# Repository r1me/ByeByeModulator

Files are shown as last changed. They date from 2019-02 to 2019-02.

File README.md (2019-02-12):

# ByeByeModulator
Modulator replacement for Commodore 64. The idea of this small board is to improve picture quality by removing noise that is caused by an RF modulator and its old electronic components. Including capacitors that can't be accessed easily for replacement, without desoldering a modulator first.  
This board is designed for, and tested with **250469 rev. B motherboard**. Do **NOT** even attempt to install it in other motherboards i.e. the one with 656x VIC-II chip. I'm not responsible for any damage.

## Board
It is a single sided, DIY friendly board.  
[Schematic](ByeByeModulator-schematic.pdf)  
[Back side for print](ByeByeModulator-board.png)  
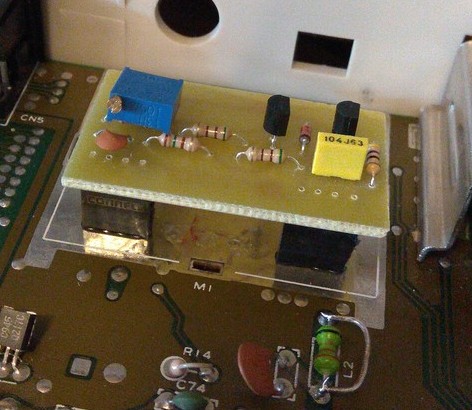
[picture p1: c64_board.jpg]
board-installed
  

## Results
Before & after
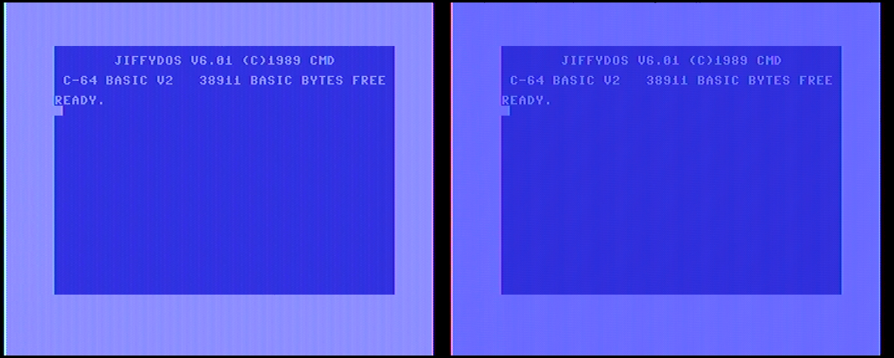
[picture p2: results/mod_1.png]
result-1
  
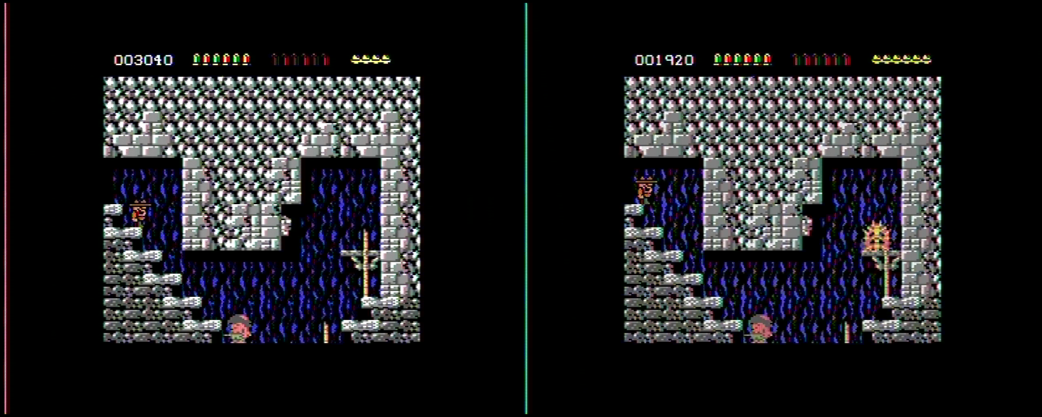
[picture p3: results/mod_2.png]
result-2
  
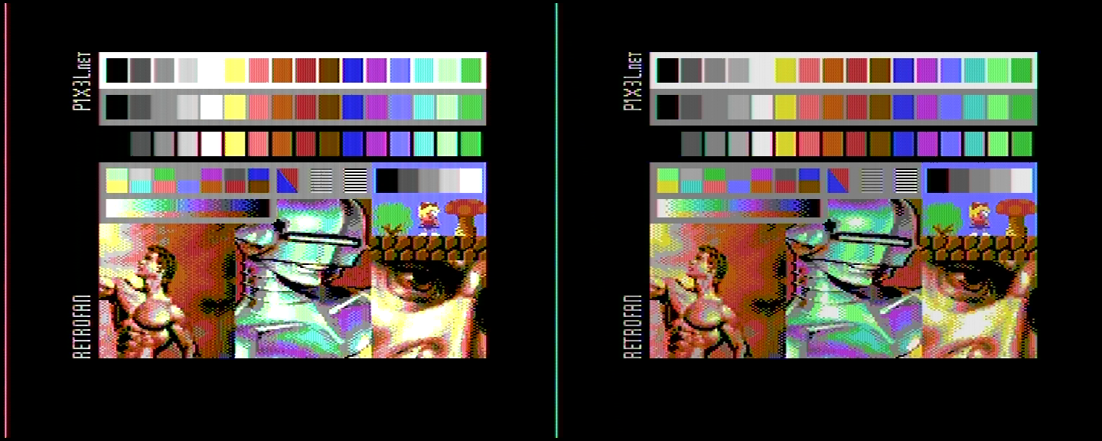
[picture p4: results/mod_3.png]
result-3
  
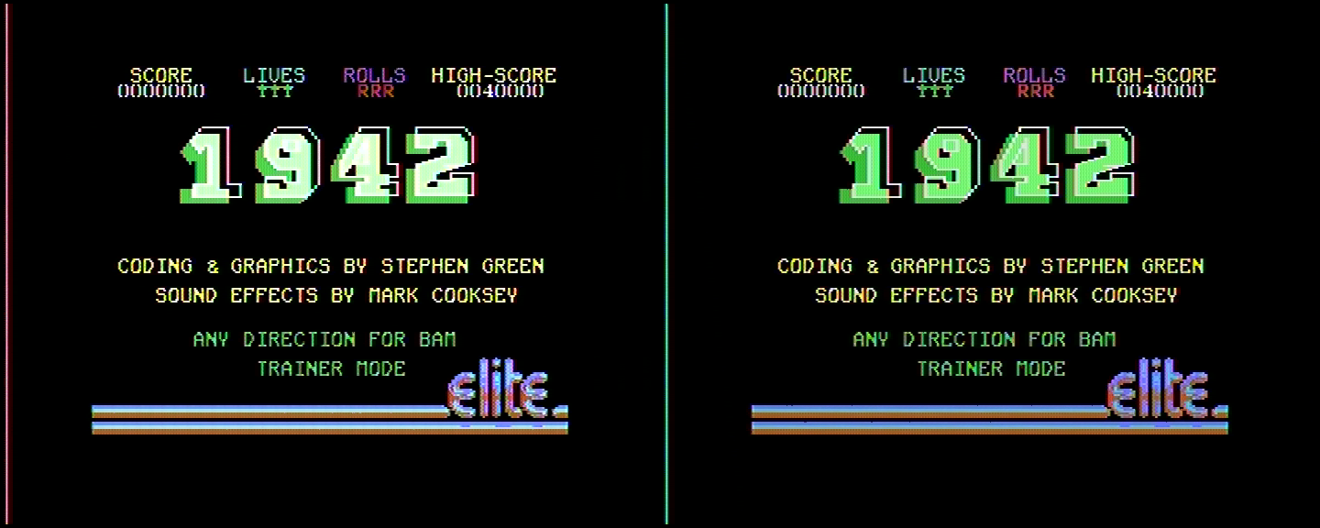
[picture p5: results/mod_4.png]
result-4
  
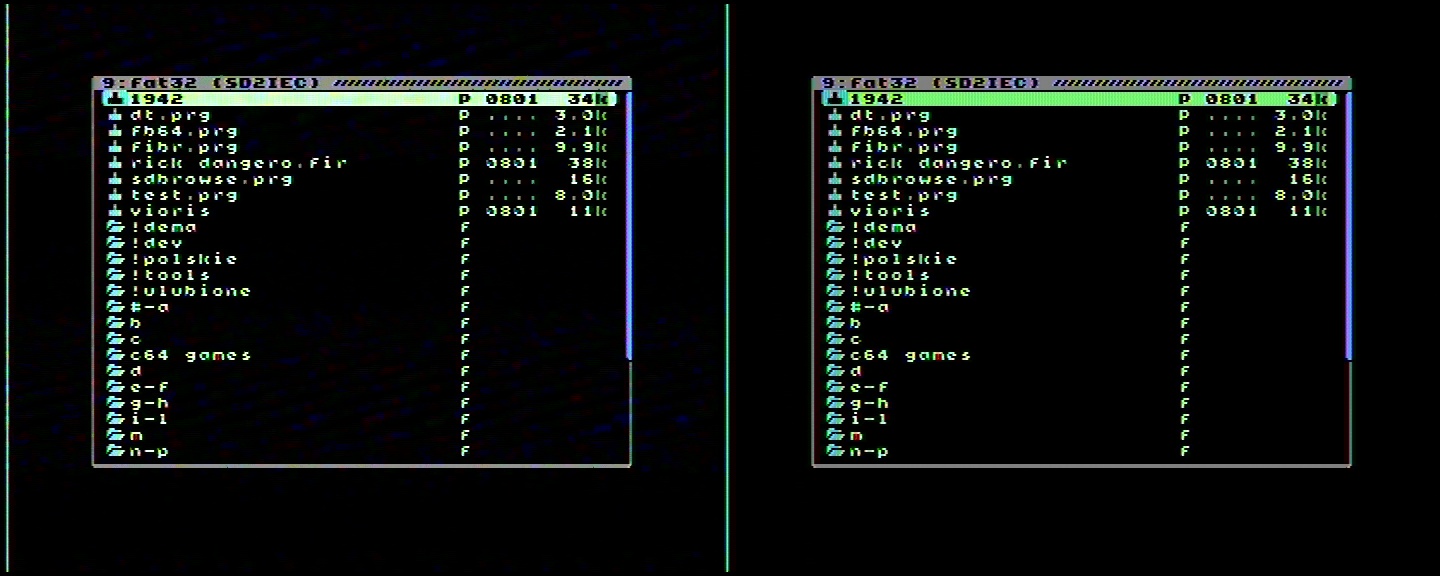
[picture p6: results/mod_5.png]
result-5
  

What I personally like about result is: rich colors (mostly yellow and green), not over-bright, and much cleaner text in the BASIC. There is some weird "wave" pattern going on, that I tried to fix by shortening L2 on C64 motherboard, it helped a bit.

## Space for improvement (aka work in progress)
If you have any idea how to improve this board, but at the same time keep it as simple as possible - feel free to fork this repository.

Thanks to aniol @ [c64scene.pl](http://www.c64scene.pl).

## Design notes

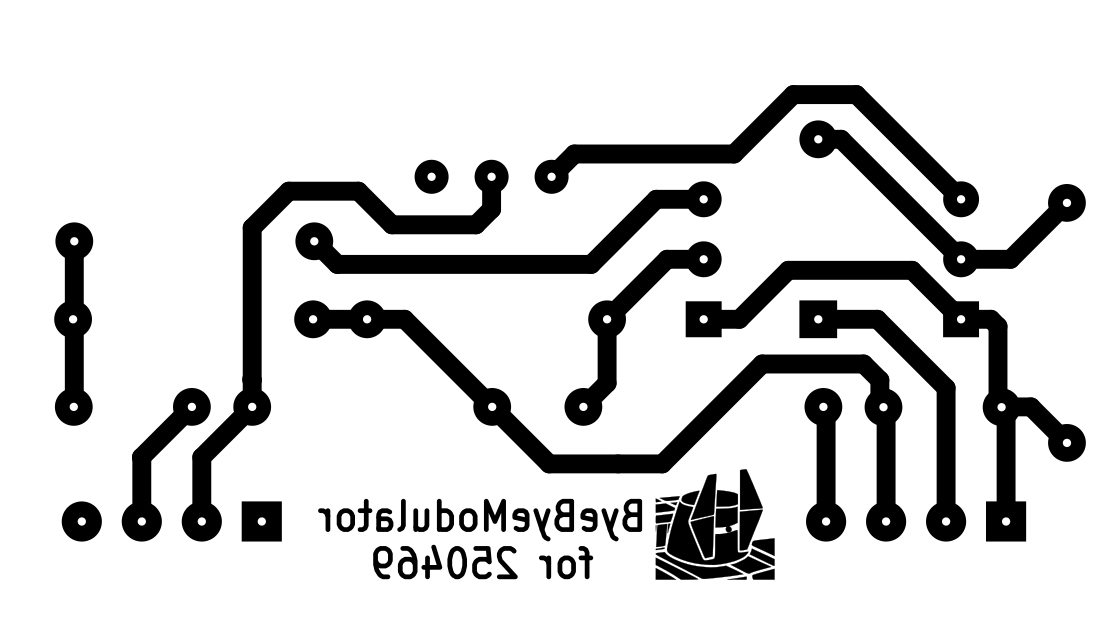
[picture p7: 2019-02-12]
ByeByeModulator-board.png

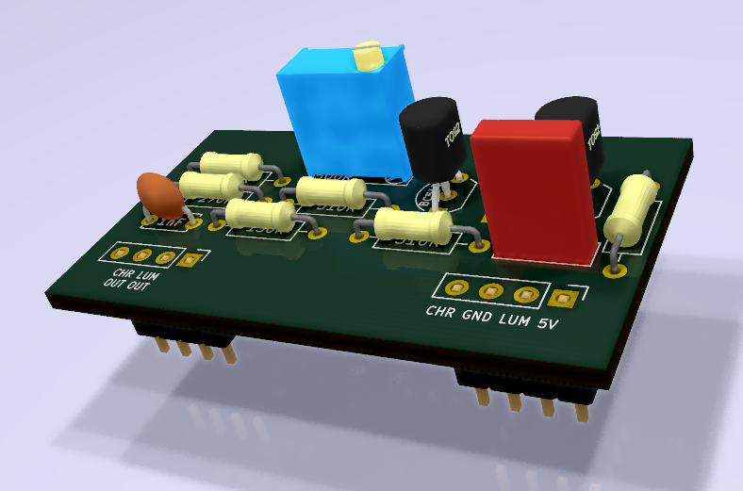
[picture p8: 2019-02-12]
3d.png

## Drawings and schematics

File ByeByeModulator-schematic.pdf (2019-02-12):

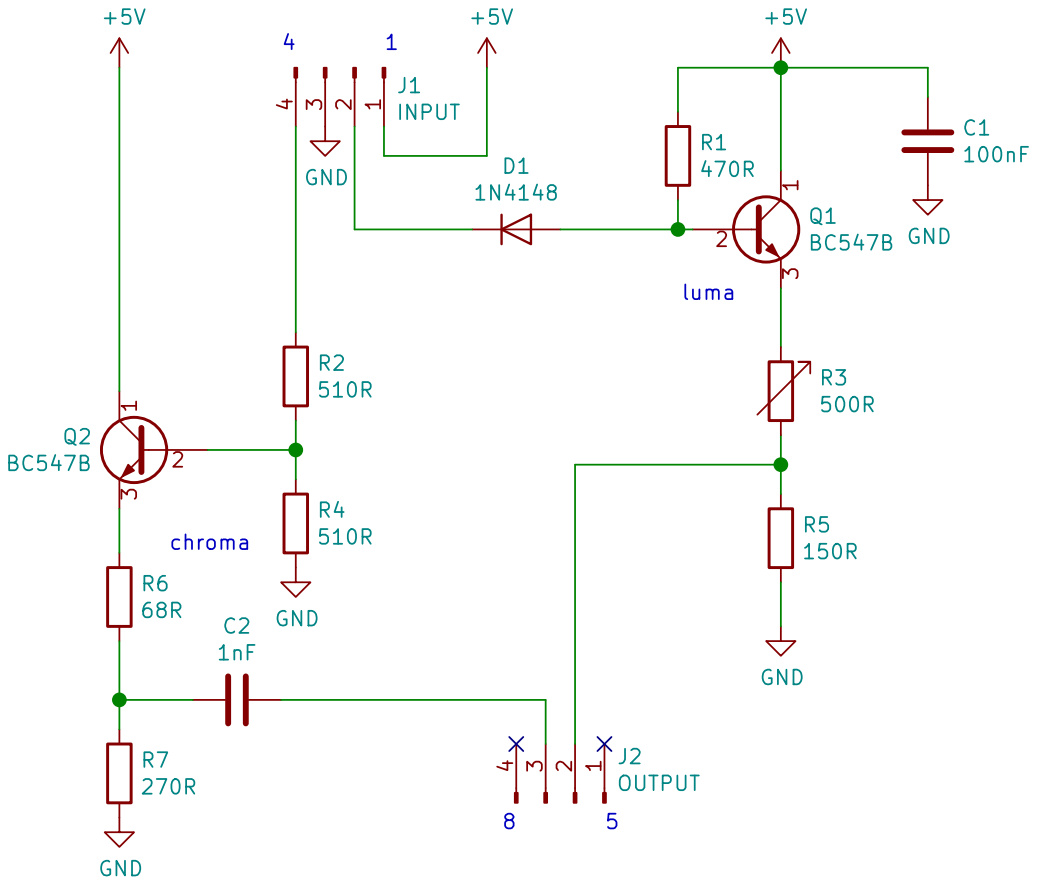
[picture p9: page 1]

File: ByeByeModulator.sch Sheet: /
Id: 1/1 Title:

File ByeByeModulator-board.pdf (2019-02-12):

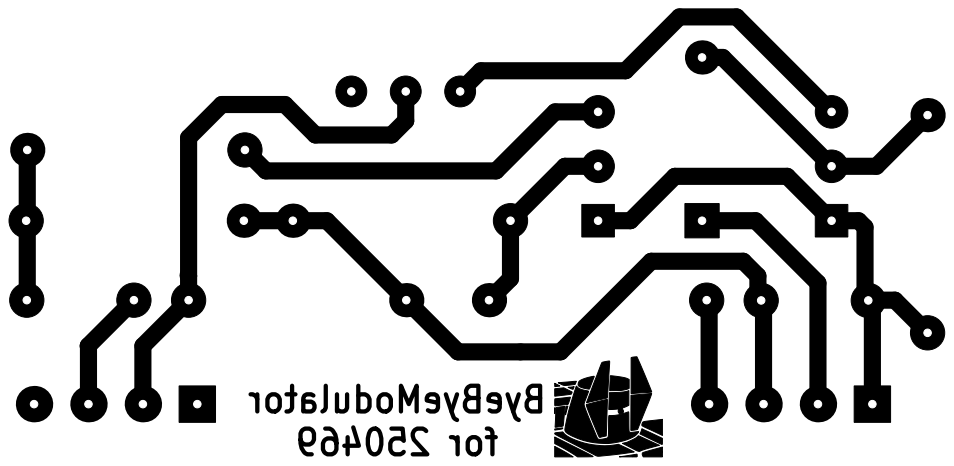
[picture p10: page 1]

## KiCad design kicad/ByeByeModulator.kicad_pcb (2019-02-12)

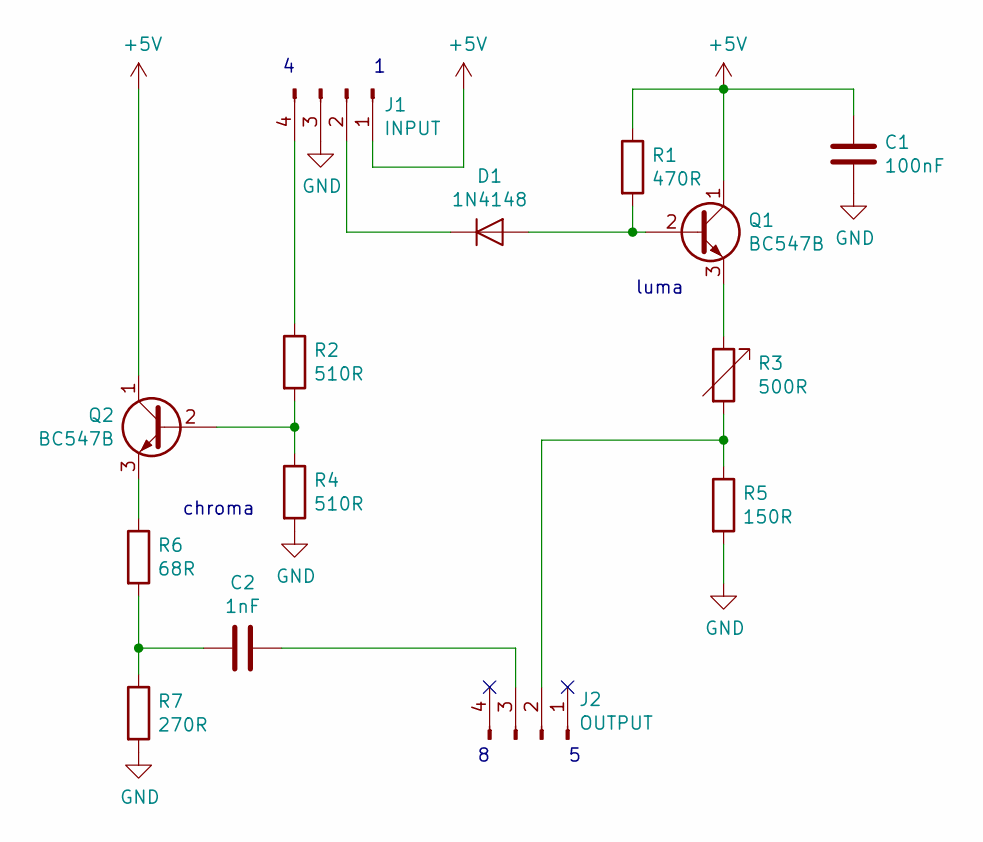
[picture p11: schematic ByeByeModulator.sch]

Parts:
C1: 100nF; C_Rect_L7.0mm_W2.5mm_P5.00mm
C2: 1nF; C_Disc_D5.0mm_W2.5mm_P5.00mm
D1: 1N4148; D_DO-35_SOD27_P7.62mm_Horizontal
J1: INPUT; Pin_Header_Straight_1x04_Pitch2.54mm
J2: OUTPUT; Pin_Header_Straight_1x04_Pitch2.54mm
Q1, Q2: BC547B; TO-92_Inline_Wide
R1: 470R; R_Axial_DIN0207_L6.3mm_D2.5mm_P10.16mm_Horizontal
R2, R4: 510R; R_Axial_DIN0207_L6.3mm_D2.5mm_P10.16mm_Horizontal
R3: 500R; Potentiometer_Trimmer_Bourns_3296W
R5: 150R; R_Axial_DIN0207_L6.3mm_D2.5mm_P10.16mm_Horizontal
R6: 68R; R_Axial_DIN0207_L6.3mm_D2.5mm_P10.16mm_Horizontal
R7: 270R; R_Axial_DIN0207_L6.3mm_D2.5mm_P10.16mm_Horizontal

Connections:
+5V: C1.1, J1.1, Q1.1 (C), Q2.1 (C), R1.1
GND: C1.2, J1.3, R4.2, R5.2, R7.2
unnamed: C2.1, J2.3
unnamed: C2.2, R6.2, R7.1
unnamed: D1.1 (K), J1.2
unnamed: D1.2 (A), Q1.2 (B), R1.2
unnamed: J1.4, R2.1
unnamed: J2.2, R3.2, R5.1
unnamed: Q1.3 (E), R3.1
unnamed: Q2.2 (B), R2.2, R4.1
unnamed: Q2.3 (E), R6.1

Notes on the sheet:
chroma
luma

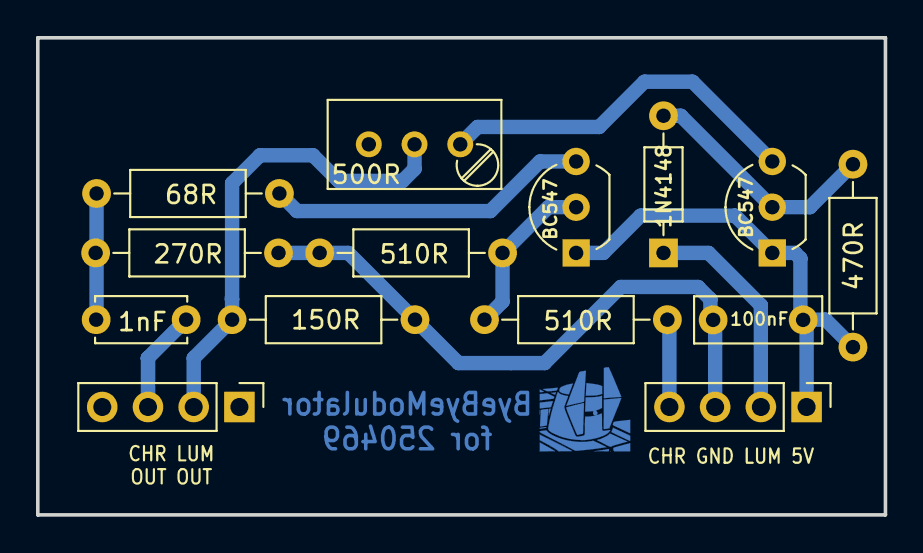
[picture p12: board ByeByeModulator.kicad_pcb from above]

Board: 2 copper layers, 47.1 x 26.5 mm, 14 parts (0 on the bottom side), 11 nets.
